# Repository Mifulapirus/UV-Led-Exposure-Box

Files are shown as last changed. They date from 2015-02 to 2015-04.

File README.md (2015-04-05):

# README #

UV LED exposure box

### What is this repository for? ###

* This project contains all the required information, hardware and software to make your own UV LED exposure machine so you can create your own PCBs at home.

### Materials ###
* Here is the list of all the different parts you need to build your own UV-LED Exposure Box
* https://docs.google.com/spreadsheets/d/1VbFTGXd1PagAe3uoOmZKsPFVGucdBjDqCyi8I9-2VKY/edit?usp=sharing

### Contact ###
* @mifulapirus

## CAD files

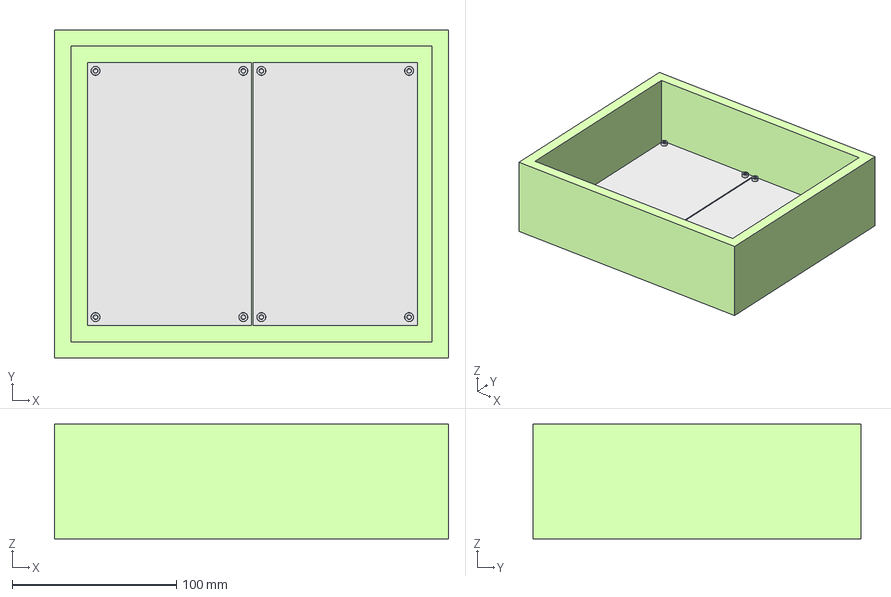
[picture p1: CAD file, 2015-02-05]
Hardware/Box/Bottom.FCStd
240.0 x 200.0 x 70.0 mm
PCB1_Completa
PCB2_Completa

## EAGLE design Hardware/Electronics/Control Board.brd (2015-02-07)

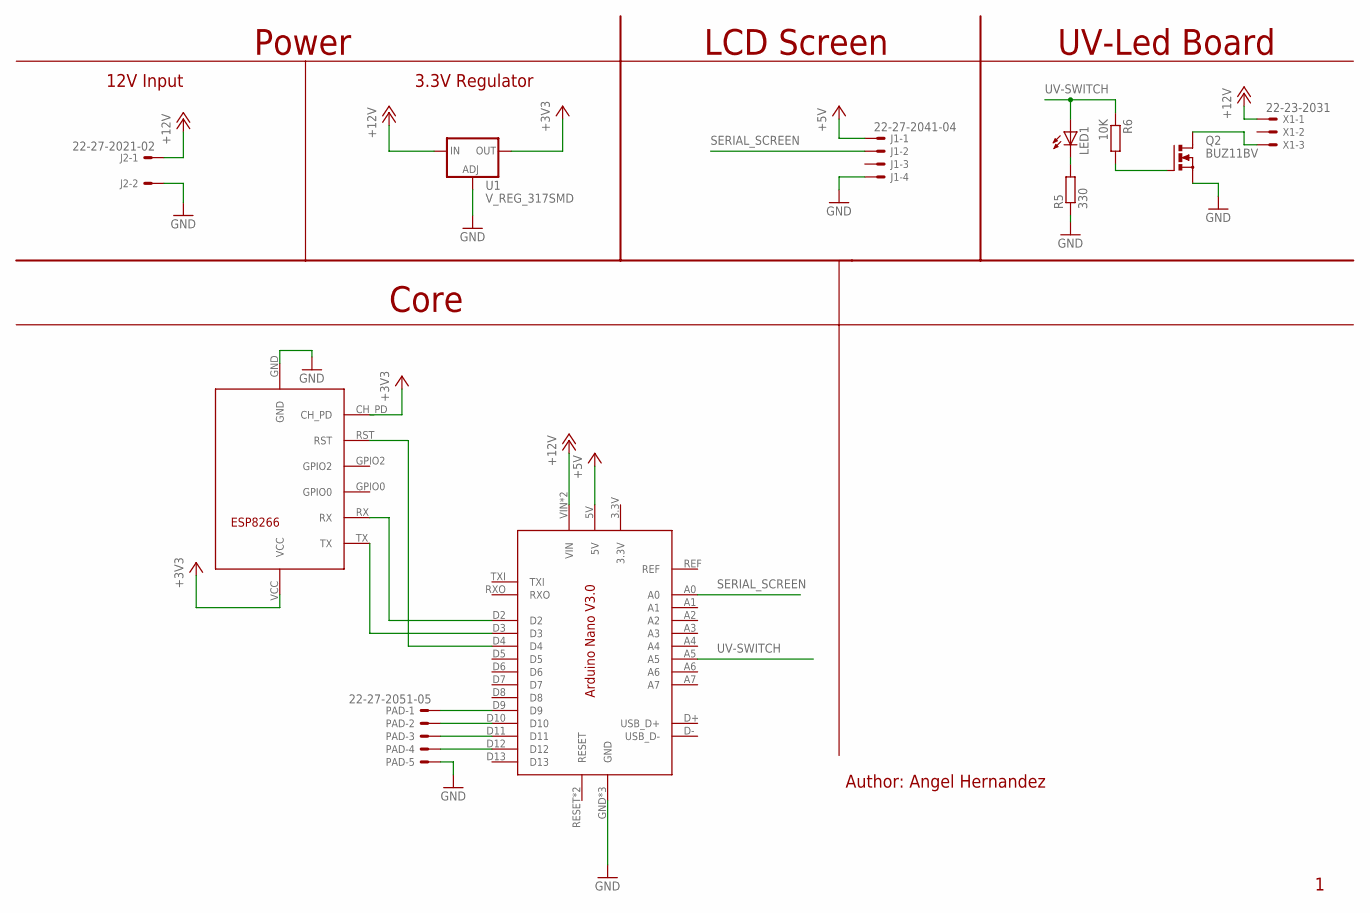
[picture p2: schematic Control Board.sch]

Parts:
J1: 22-27-2041-04; 6410-04
J2: 22-27-2021-02; 6410-02
LED1: LED3MM
PAD: 22-27-2051-05; 6410-05
Q2: BUZ11BV; TO220BV
R5: 330; 0204/7
R6: 10K; 0204/7
U1: V_REG_317SMD; SOT223
U$1: ARDUINO_NANO_V3
U$2: ESP8266
X1: 22-23-2031

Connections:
+3V3: U1.2 (OUT), U$2.CH_PD, U$2.VCC
+5V: J1.1, U$1.5V
+12V: J2.1, U1.3 (IN), U$1.VIN, U$1.VUSB (VIN), X1.1
GND: J1.4, J2.2, PAD.5, Q2.S, R5.1, U1.1 (ADJ), U$1.GND, U$1.GND1 (GND), U$1.GND_USB (GND), U$2.GND
unnamed: Q2.D, X1.3
unnamed: U$1.D3, U$2.TX
unnamed: U$1.D2, U$2.RX
unnamed: PAD.1, U$1.D9
unnamed: PAD.2, U$1.D10
unnamed: PAD.3, U$1.D11
unnamed: PAD.4, U$1.D12
unnamed: LED1.K (C), R5.2
unnamed: Q2.G, R6.2
unnamed: U$1.D4, U$2.RST
SERIAL_SCREEN: J1.2, U$1.A0
UV-SWITCH: LED1.A, R6.1, U$1.A5

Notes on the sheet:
UV-Led Board
Power
LCD Screen
Author: Angel Hernandez
12V Input
3.3V Regulator
Core

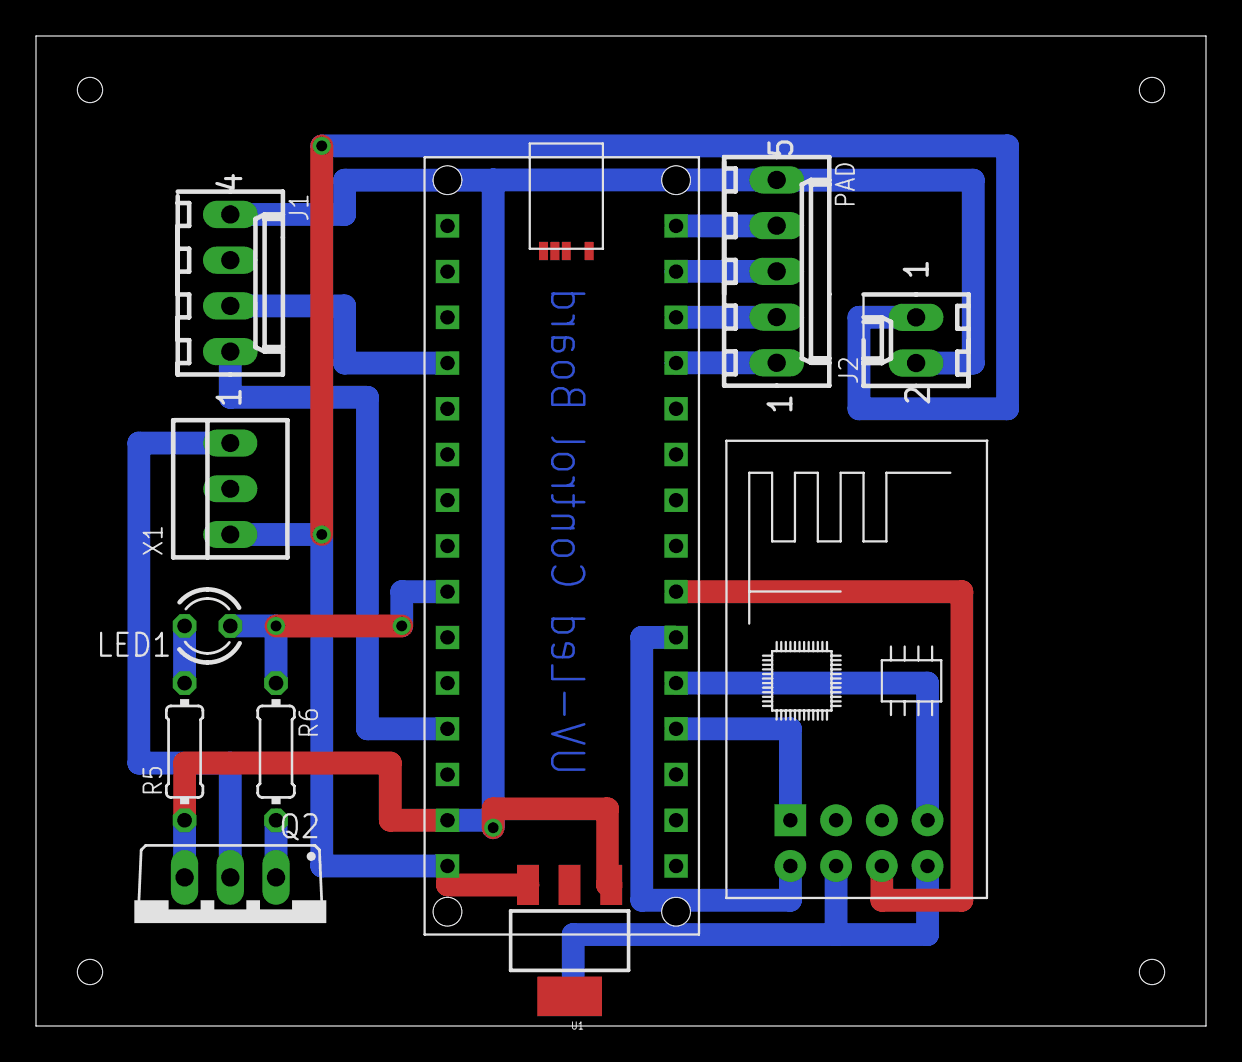
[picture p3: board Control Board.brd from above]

Board: 2 copper layers, 65.0 x 55.0 mm, 11 parts (0 on the bottom side), 16 nets.

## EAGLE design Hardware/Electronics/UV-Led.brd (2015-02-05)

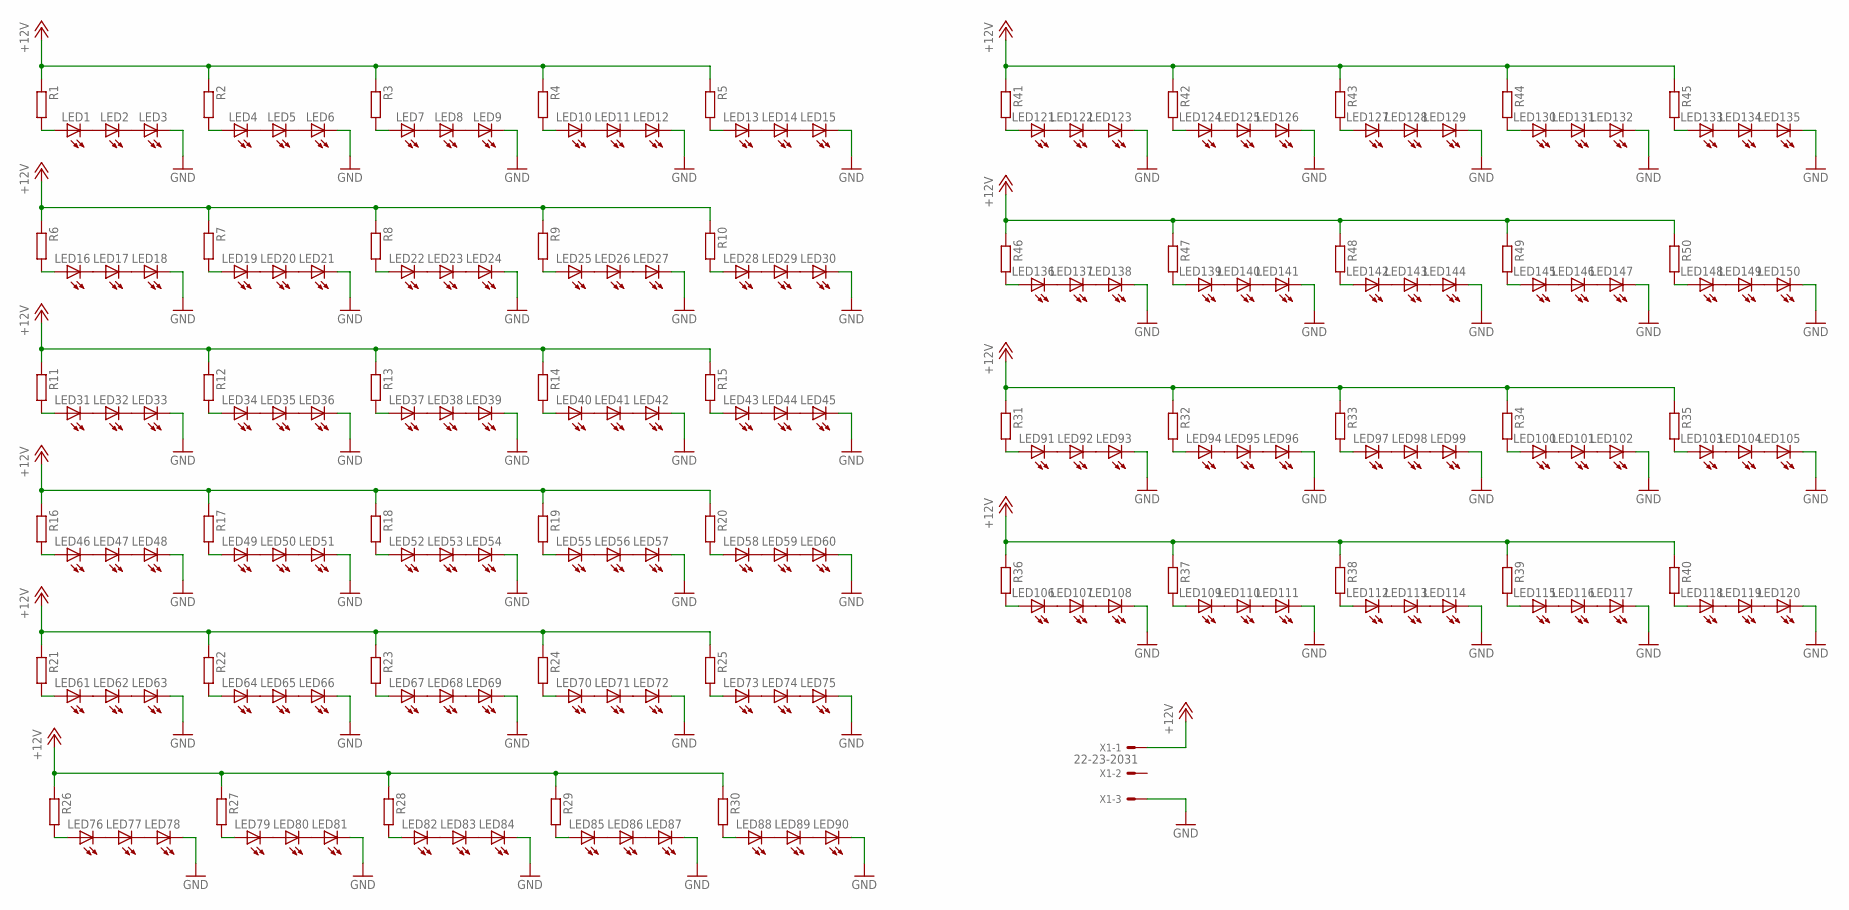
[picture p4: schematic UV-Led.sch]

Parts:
LED1, LED2, LED3, LED4, LED5, LED6, LED7, LED8, LED9, LED10, LED11, LED12, LED13, LED14, LED15, LED16, LED17, LED18, LED19, LED20, LED21, LED22, LED23, LED24, LED25, LED26, LED27, LED28, LED29, LED30, LED31, LED32, LED33, LED34, LED35, LED36, LED37, LED38, LED39, LED40, LED41, LED42, LED43, LED44, LED45, LED46, LED47, LED48, LED49, LED50, LED51, LED52, LED53, LED54, LED55, LED56, LED57, LED58, LED59, LED60, LED61, LED62, LED63, LED64, LED65, LED66, LED67, LED68, LED69, LED70, LED71, LED72, LED73, LED74, LED75, LED76, LED77, LED78, LED79, LED80, LED81, LED82, LED83, LED84, LED85, LED86, LED87, LED88, LED89, LED90, LED91, LED92, LED93, LED94, LED95, LED96, LED97, LED98, LED99, LED100, LED101, LED102, LED103, LED104, LED105, LED106, LED107, LED108, LED109, LED110, LED111, LED112, LED113, LED114, LED115, LED116, LED117, LED118, LED119, LED120, LED121, LED122, LED123, LED124, LED125, LED126, LED127, LED128, LED129, LED130, LED131, LED132, LED133, LED134, LED135, LED136, LED137, LED138, LED139, LED140, LED141, LED142, LED143, LED144, LED145, LED146, LED147, LED148, LED149, LED150: LED5MM
R1, R2, R3, R4, R5, R6, R7, R8, R9, R10, R11, R12, R13, R14, R15, R16, R17, R18, R19, R20, R21, R22, R23, R24, R25, R26, R27, R28, R29, R30, R31, R32, R33, R34, R35, R36, R37, R38, R39, R40, R41, R42, R43, R44, R45, R46, R47, R48, R49, R50: R-EU_0207/10; 0207/10
X1: 22-23-2031

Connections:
+12V: R1.1, R2.1, R3.1, R4.1, R5.1, R6.1, R7.1, R8.1, R9.1, R10.1, R11.1, R12.1, R13.1, R14.1, R15.1, R16.1, R17.1, R18.1, R19.1, R20.1, R21.1, R22.1, R23.1, R24.1, R25.1, R26.1, R27.1, R28.1, R29.1, R30.1, R31.1, R32.1, R33.1, R34.1, R35.1, R36.1, R37.1, R38.1, R39.1, R40.1, R41.1, R42.1, R43.1, R44.1, R45.1, R46.1, R47.1, R48.1, R49.1, R50.1, X1.1
GND: LED3.K (C), LED6.K (C), LED9.K (C), LED12.K (C), LED15.K (C), LED18.K (C), LED21.K (C), LED24.K (C), LED27.K (C), LED30.K (C), LED33.K (C), LED36.K (C), LED39.K (C), LED42.K (C), LED45.K (C), LED48.K (C), LED51.K (C), LED54.K (C), LED57.K (C), LED60.K (C), LED63.K (C), LED66.K (C), LED69.K (C), LED72.K (C), LED75.K (C), LED78.K (C), LED81.K (C), LED84.K (C), LED87.K (C), LED90.K (C), LED93.K (C), LED96.K (C), LED99.K (C), LED102.K (C), LED105.K (C), LED108.K (C), LED111.K (C), LED114.K (C), LED117.K (C), LED120.K (C), LED123.K (C), LED126.K (C), LED129.K (C), LED132.K (C), LED135.K (C), LED138.K (C), LED141.K (C), LED144.K (C), LED147.K (C), LED150.K (C), X1.3
unnamed: LED1.K (C), LED2.A
unnamed: LED2.K (C), LED3.A
unnamed: LED4.K (C), LED5.A
unnamed: LED5.K (C), LED6.A
unnamed: LED7.K (C), LED8.A
unnamed: LED8.K (C), LED9.A
unnamed: LED1.A, R1.2
unnamed: LED4.A, R2.2
unnamed: LED7.A, R3.2
unnamed: LED13.K (C), LED14.A
unnamed: LED10.K (C), LED11.A
unnamed: LED11.K (C), LED12.A
unnamed: LED10.A, R4.2
unnamed: LED14.K (C), LED15.A
unnamed: LED13.A, R5.2
unnamed: LED16.K (C), LED17.A
unnamed: LED17.K (C), LED18.A
unnamed: LED19.K (C), LED20.A
unnamed: LED20.K (C), LED21.A
unnamed: LED22.K (C), LED23.A
unnamed: LED23.K (C), LED24.A
unnamed: LED16.A, R6.2
unnamed: LED19.A, R7.2
unnamed: LED22.A, R8.2
unnamed: LED25.K (C), LED26.A
unnamed: LED26.K (C), LED27.A
unnamed: LED28.K (C), LED29.A
unnamed: LED29.K (C), LED30.A
unnamed: LED25.A, R9.2
unnamed: LED28.A, R10.2
unnamed: LED31.K (C), LED32.A
unnamed: LED32.K (C), LED33.A
unnamed: LED34.K (C), LED35.A
unnamed: LED35.K (C), LED36.A
unnamed: LED37.K (C), LED38.A
unnamed: LED38.K (C), LED39.A
unnamed: LED31.A, R11.2
unnamed: LED34.A, R12.2
unnamed: LED37.A, R13.2
unnamed: LED40.K (C), LED41.A
unnamed: LED41.K (C), LED42.A
unnamed: LED43.K (C), LED44.A
unnamed: LED44.K (C), LED45.A
unnamed: LED40.A, R14.2
unnamed: LED43.A, R15.2
unnamed: LED46.K (C), LED47.A
unnamed: LED47.K (C), LED48.A
unnamed: LED49.K (C), LED50.A
unnamed: LED50.K (C), LED51.A
unnamed: LED52.K (C), LED53.A
unnamed: LED53.K (C), LED54.A
unnamed: LED46.A, R16.2
unnamed: LED49.A, R17.2
unnamed: LED52.A, R18.2
unnamed: LED55.K (C), LED56.A
unnamed: LED56.K (C), LED57.A
unnamed: LED58.K (C), LED59.A
unnamed: LED59.K (C), LED60.A
unnamed: LED55.A, R19.2
unnamed: LED58.A, R20.2
unnamed: LED61.K (C), LED62.A
unnamed: LED62.K (C), LED63.A
unnamed: LED64.K (C), LED65.A
unnamed: LED65.K (C), LED66.A
unnamed: LED67.K (C), LED68.A
unnamed: LED68.K (C), LED69.A
unnamed: LED61.A, R21.2
unnamed: LED64.A, R22.2
unnamed: LED67.A, R23.2
unnamed: LED70.K (C), LED71.A
unnamed: LED71.K (C), LED72.A
unnamed: LED73.K (C), LED74.A
unnamed: LED74.K (C), LED75.A
unnamed: LED70.A, R24.2
unnamed: LED73.A, R25.2
unnamed: LED76.K (C), LED77.A
unnamed: LED77.K (C), LED78.A
unnamed: LED79.K (C), LED80.A
unnamed: LED80.K (C), LED81.A
unnamed: LED82.K (C), LED83.A
unnamed: LED83.K (C), LED84.A
unnamed: LED76.A, R26.2
unnamed: LED79.A, R27.2
unnamed: LED82.A, R28.2
unnamed: LED85.K (C), LED86.A
unnamed: LED86.K (C), LED87.A
unnamed: LED88.K (C), LED89.A
unnamed: LED89.K (C), LED90.A
unnamed: LED85.A, R29.2
unnamed: LED88.A, R30.2
unnamed: LED91.K (C), LED92.A
unnamed: LED92.K (C), LED93.A
unnamed: LED94.K (C), LED95.A
unnamed: LED95.K (C), LED96.A
unnamed: LED97.K (C), LED98.A
unnamed: LED98.K (C), LED99.A
unnamed: LED91.A, R31.2
unnamed: LED94.A, R32.2
unnamed: LED97.A, R33.2
unnamed: LED100.K (C), LED101.A
unnamed: LED101.K (C), LED102.A
unnamed: LED103.K (C), LED104.A
unnamed: LED104.K (C), LED105.A
unnamed: LED100.A, R34.2
unnamed: LED103.A, R35.2
unnamed: LED106.K (C), LED107.A
unnamed: LED107.K (C), LED108.A
unnamed: LED109.K (C), LED110.A
unnamed: LED110.K (C), LED111.A
unnamed: LED112.K (C), LED113.A
unnamed: LED113.K (C), LED114.A
unnamed: LED106.A, R36.2
unnamed: LED109.A, R37.2
unnamed: LED112.A, R38.2
unnamed: LED115.K (C), LED116.A
unnamed: LED116.K (C), LED117.A
unnamed: LED118.K (C), LED119.A
unnamed: LED119.K (C), LED120.A
unnamed: LED115.A, R39.2
unnamed: LED118.A, R40.2
unnamed: LED121.K (C), LED122.A
unnamed: LED122.K (C), LED123.A
unnamed: LED124.K (C), LED125.A
unnamed: LED125.K (C), LED126.A
unnamed: LED127.K (C), LED128.A
unnamed: LED128.K (C), LED129.A
unnamed: LED121.A, R41.2
unnamed: LED124.A, R42.2
unnamed: LED127.A, R43.2
unnamed: LED130.K (C), LED131.A
unnamed: LED131.K (C), LED132.A
unnamed: LED133.K (C), LED134.A
unnamed: LED134.K (C), LED135.A
unnamed: LED130.A, R44.2
unnamed: LED133.A, R45.2
unnamed: LED136.K (C), LED137.A
unnamed: LED137.K (C), LED138.A
unnamed: LED139.K (C), LED140.A
unnamed: LED140.K (C), LED141.A
unnamed: LED142.K (C), LED143.A
unnamed: LED143.K (C), LED144.A
unnamed: LED136.A, R46.2
unnamed: LED139.A, R47.2
unnamed: LED142.A, R48.2
unnamed: LED145.K (C), LED146.A
unnamed: LED146.K (C), LED147.A
unnamed: LED148.K (C), LED149.A
unnamed: LED149.K (C), LED150.A
unnamed: LED145.A, R49.2
unnamed: LED148.A, R50.2

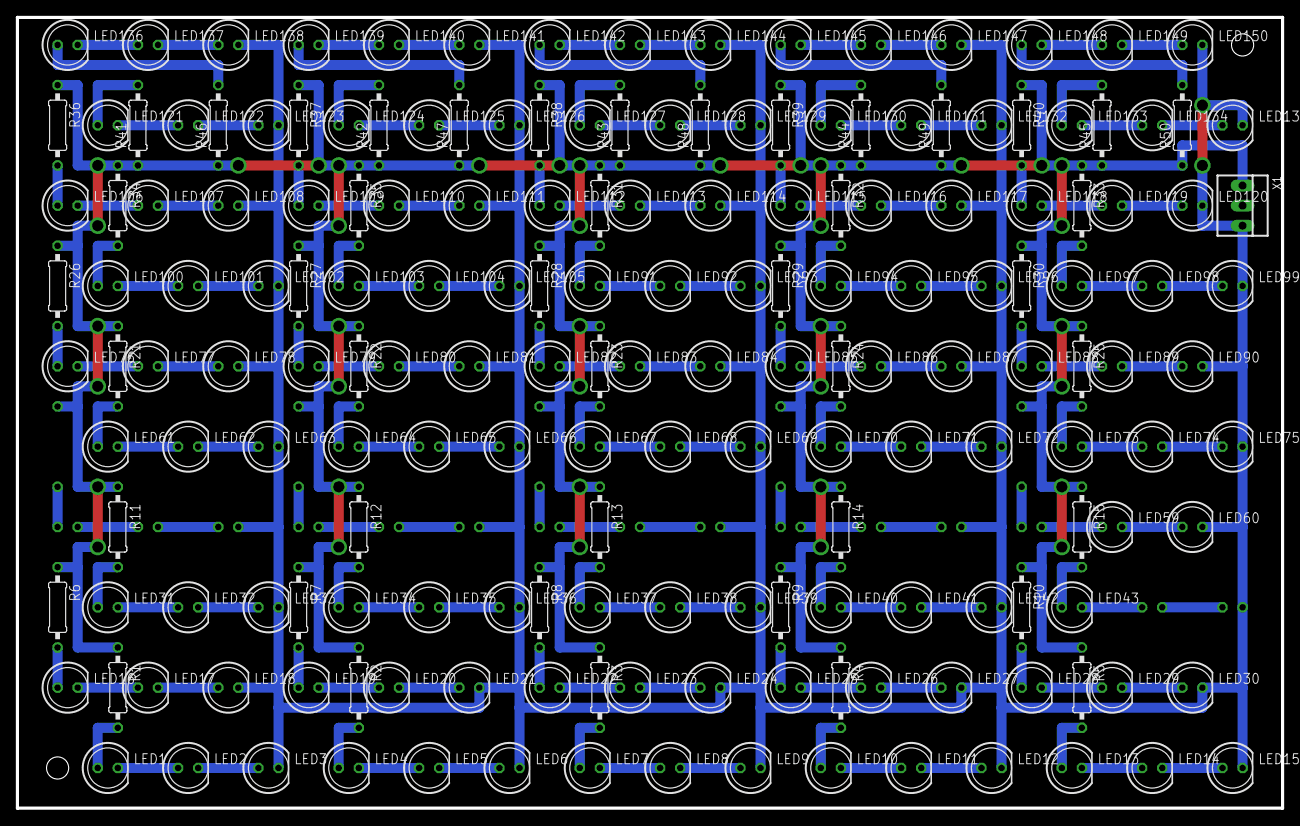
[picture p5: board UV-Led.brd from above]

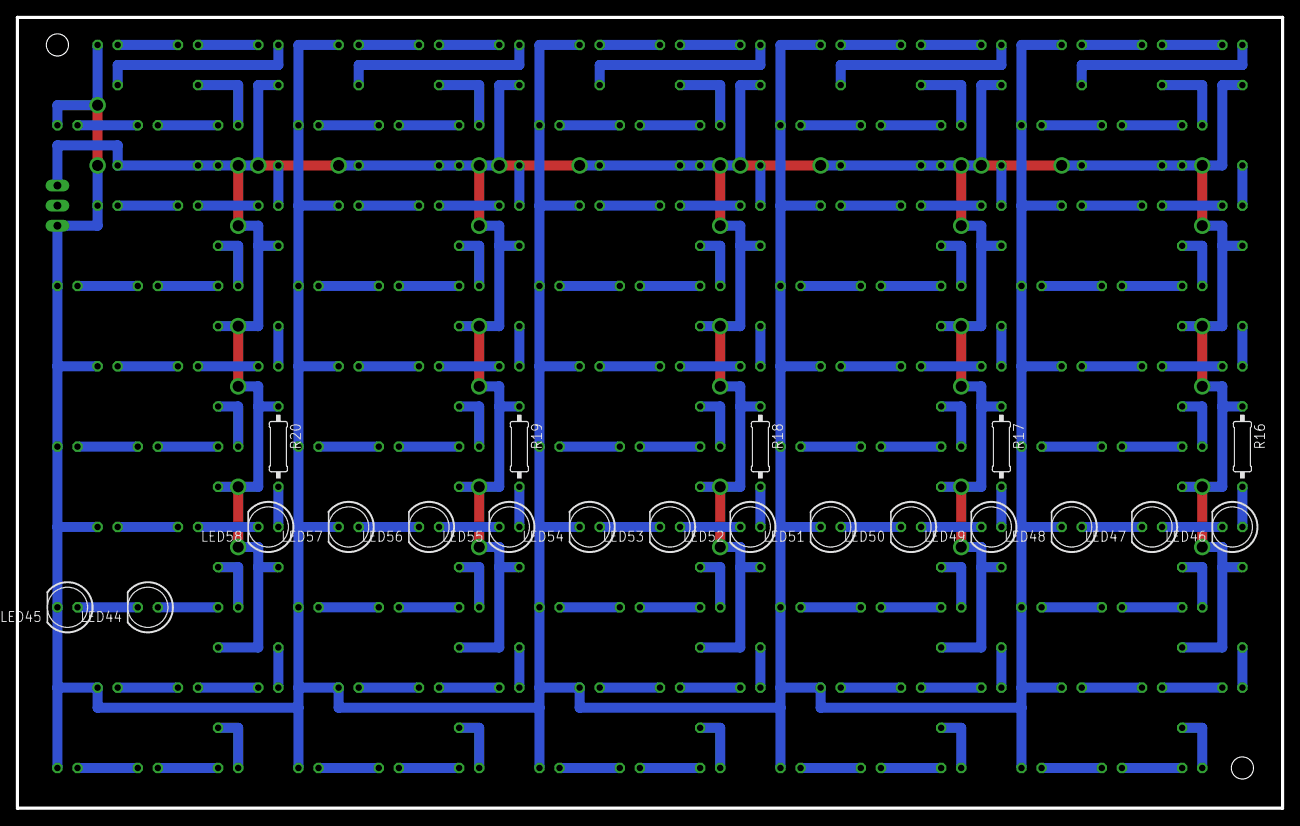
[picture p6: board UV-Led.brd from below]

Board: 2 copper layers, 160.0 x 100.0 mm, 201 parts (20 on the bottom side), 152 nets.

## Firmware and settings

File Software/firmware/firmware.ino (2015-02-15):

#include <SoftwareSerial.h>
#include <ESP8266.h>
#include <serLCD.h>

/*******************************
* Pin definitions
*******************************/
#define DISPLAY_PIN   A1

#define PAD_UP_PIN    9
#define PAD_DOWN_PIN  10
#define PAD_LEFT_PIN  11
#define PAD_RIGHT_PIN 12

#define UV_SWITCH_PIN A5

#define WIFI_RX_PIN 2
#define WIFI_TX_PIN 3
#define WIFI_RST_PIN 4

/*******************************
* General variables
*******************************/
#define FIRMWARE_VERSION   "0.2"
#define DEVICE_CATEGORY    "UV Exposure Box" 
#define DEVICE_NAME        "UV Exposure Box"
long timerStartedTime = 0;
long timerLastUpdate   = 0;
long timerValue       = 10000;         //10 seconds
boolean timerStarted = false;

/*****************************
* Other devices
*****************************/
serLCD lcd(DISPLAY_PIN);

/*******************************
* WiFi Stuff
*******************************/
#define BAUD 9600
#define SSID "Interne"
#define PASS "Mec0mebien"
#define SERVER_PORT  "5555"
ESP8266 wifi(WIFI_RX_PIN, WIFI_TX_PIN, WIFI_RST_PIN, BAUD);

/****************************
* Control Commands
****************************/
#define CMD_UV_ON    "UV:On"
#define CMD_UV_OFF   "UV:Off"
#define CMD_UV_TEST  "UV:Test"
#define CMD_TIMER_ON  "Timer:On"
#define CMD_TIMER_ON  "Timer:Off"
#define CMD_SET_TIMER  "SetTimer"
#define CMD_START_TIMER  "StartTimer"
#define CMD_STOP_TIMER  "StopTimer"

/****************************
* Configuration Commands
****************************/
#define CMD_WIFI_SSID  "SetSSID"
#define CMD_WIFI_PASS  "SetPass"



/************************************
* Setup and initializations
************************************/  
void setup() {
  //Set input pins
  pinMode(PAD_UP_PIN, INPUT);
  pinMode(PAD_DOWN_PIN, INPUT);
  pinMode(PAD_LEFT_PIN, INPUT);
  pinMode(PAD_RIGHT_PIN, INPUT);
  //Set output pins
  pinMode(WIFI_RST_PIN, OUTPUT);
  pinMode(UV_SWITCH_PIN, OUTPUT);
  
  //Initialize navite serial port
  Serial.begin(9600);
  lcd.clear();
  delay(1000);
  bootUp(); 
}


/************************************
* printing and reporting
************************************/
void lcdAndSerialPrint(String _text) {
  lcd.print(_text);
  Serial.println(_text);
}


/************************************
* General Functions
************************************/
void loop() {
  receiveCommand();
  checkUVTimer();
}

//Bootup sequence
void bootUp() {
  int _err = -1;
  int Err = -1;
  lcd.clear();
  lcdAndSerialPrint(DEVICE_NAME);
  lcd.selectLine(2);
  lcdAndSerialPrint("Version: ");
  lcdAndSerialPrint(FIRMWARE_VERSION);
  
  delay(1000);
  lcd.clear();
  lcdAndSerialPrint("UV Test -> ");
  UVSwithTest();
  lcdAndSerialPrint("Done");
  delay(1000);
  
  lcd.clear();
  lcdAndSerialPrint("Initializing");
  lcd.selectLine(2);
  lcdAndSerialPrint("WiFi ESP8266");
  _err = wifi.init(SSID, PASS);
  if(_err != NO_ERROR) {
    lcdAndSerialPrint("Error: ");
    lcdAndSerialPrint(String(_err));
    delay(3000);
  }
  
  else{
    lcd.clear();
    lcdAndSerialPrint("Connected: ");
    lcd.selectLine(2);
    lcdAndSerialPrint(wifi.IP);
    delay(2000);  
  }
     
  _err = wifi.setServer(SERVER_PORT);
  if(_err != NO_ERROR) {
    lcd.clear();
    lcdAndSerialPrint("Error: ");
    lcdAndSerialPrint(String(_err));
  }
  
  else{
    lcd.clear();
    lcdAndSerialPrint("Server OK: ");
    lcdAndSerialPrint(wifi.serverPort);
    
    delay(1000);
    lcd.clear();
    lcdAndSerialPrint(DEVICE_NAME);
    lcd.selectLine(2);
    lcdAndSerialPrint("     ONLINE");  
  }    
}


/**************************************************************************************
* Command functions
***************************************************************************************/
int receiveCommand() {
  String _cmd = wifi.readCmd();
  if (_cmd == "") return false;
  if (_cmd == CMD_UV_ON)                  return setUV(true);
  else if (_cmd == CMD_UV_OFF)            return setUV(false);
  else if (_cmd == CMD_UV_TEST)           return UVSwithTest();
  else if (contains(_cmd, CMD_SET_TIMER)) return setTimer(extractParam(_cmd).toInt());
  else if (_cmd == CMD_START_TIMER)       return startTimer();
  else if (_cmd == CMD_STOP_TIMER)        return stopTimer();
  else return false;
}

boolean contains(String _original, String _search) {
    int _searchLength = _search.length();
	int _max = _original.length() - _searchLength;
    for (int i = 0; i <= _max; i++) {
        if (_original.substring(i, i+_searchLength) == _search) {return true;}
    }
    return false;
} 

//Extracts the value of a parameter from the '=' separator till the end
String extractParam(String _cmd) {
  int _separatorIndex = _cmd.indexOf('=') + 1;
  return _cmd.substring(_separatorIndex);
}

  
/**************************************************************************************
* UV-LED Functions
***************************************************************************************/
boolean UVSwithTest() {
  for (int i=0; i<4; i++) {
   digitalWrite(UV_SWITCH_PIN, !digitalRead(UV_SWITCH_PIN));
   delay(200);
  }
  return true;
}

boolean setUV(boolean _state) {
   digitalWrite(UV_SWITCH_PIN, _state);
   getUV();
   if (digitalRead(UV_SWITCH_PIN)== _state) return true;
   else return false;
}

boolean getUV() {
  boolean _state = digitalRead(UV_SWITCH_PIN);
  lcd.setCursor(2,16);
  lcd.print(_state);
  return _state;
}

void toggleUV() {
  digitalWrite(UV_SWITCH_PIN, !digitalRead(UV_SWITCH_PIN));
}

void checkUVTimer() {
  if (timerStarted == true) {
    long _now = millis();
        
    if (_now > (timerStartedTime + timerValue - 1000)) {
      setUV(false);
      timerStarted = false;
      lcd.clear();
      lcdAndSerialPrint("Exposure DONE");
    }
    
    else if (_now >= timerLastUpdate + 1000) {  //Every second print remaining time
      timerLastUpdate = _now;
      lcd.setCursor(2,1);
      lcd.print("               ");
      lcd.setCursor(2,1);
      lcdAndSerialPrint(String((timerStartedTime + timerValue - _now)/1000));
    }  
  }
}

boolean setTimer(int _time) {
  timerValue = _time;
  timerValue = timerValue * 1000;  //time converted to ms
  lcd.setCursor(2,1);
  lcd.print("               ");
  lcd.setCursor(2,1);
  lcdAndSerialPrint(String(timerValue/1000));
  return true;
}
  
boolean startTimer() {
    timerStarted = true;
    timerStartedTime=millis();
    setUV(true);
    return true;
}

boolean stopTimer() {
    timerStarted = false;
    setUV(false);
    return true;
}

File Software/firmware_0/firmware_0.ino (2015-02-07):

#include <SoftwareSerial.h>
#include <serLCD.h>

#define display_pin A0

#define padUp_pin 9
#define padDown_pin 10
#define padLeft_pin 11
#define padRight_pin 12

#define UVSwitch_pin A5


/*******************************
* General variables
*******************************/
#define FirmwareVersion "0.1"
#define DeviceCategory "UV Exposure Box" 
int DeviceID = 1; 
#define DeviceName "UV"

/*******************************
* WiFi Stuff
*******************************/
#define wifiRx_pin 2
#define wifiTx_pin 3
#define wifiRST_pin 4

#define SSID "Interne"
#define PASS "Mec0mebien"
SoftwareSerial WiFiSerial(wifiRx_pin, wifiTx_pin); // RX, TX
String OwnIP = "000.000.000.000";
String WiFiLongMessage;

//----------------------
//Messages sent
#define ResponseOK     "OK"
#define Error          "ERROR "
  #define ErrorUnableToLink             "1"
  #define SendLongMessageError          "2"  
  #define ErrorModuleDoesntRespond      "3"
  #define ErrorModuleDoesntRespondToAT  "4"
  #define ErrorResponseNotFound         "5"
  #define ErrorUnableToConnect          "6"
  
#define CIPSTART       "AT+CIPSTART=\"TCP\",\""


serLCD lcd(display_pin);


void setup() {
  pinMode(padUp_pin, OUTPUT);
  pinMode(padDown_pin, OUTPUT);
  pinMode(padLeft_pin, OUTPUT);
  pinMode(padRight_pin, OUTPUT);
  pinMode(wifiRST_pin, OUTPUT);
  pinMode(UVSwitch_pin, OUTPUT);
  
  Serial.begin(9600);
  WiFiSerial.begin(9600);
  
  Serial.println(DeviceName);
  Serial.println(DeviceCategory);
  Serial.print("V. ");
  Serial.println(FirmwareVersion);
  Serial.print("ID: ");
  Serial.println(DeviceID);
  //Attach the interruption
//  attachInterrupt(0, FireDetected, RISING);
  WiFiLongMessage.reserve(400);
  lcd.clear();
  lcd.print(DeviceCategory);
  lcd.print(" ");
  lcd.print(FirmwareVersion);
  UVSwithTest();
  
  InitWiFi();
  lcd.print(" WiFi: Online");
}

/************************************
* General Functions
************************************/
void loop() {

}

void PrintError(char* ErrorMessage) {
  Serial.print(Error);
  Serial.println(ErrorMessage);
  }


/**************************************************************************************
* UV-LED Functions
***************************************************************************************/
void UVSwithTest() {
  for (int i=0; i<6; i++) {
   digitalWrite(UVSwitch_pin, !digitalRead(UVSwitch_pin));
   delay(500);
   }
}

/**************************************************************************************
* WiFi Functions
***************************************************************************************/
boolean OpenTCP(String IP, String Port) {
  String cmd = CIPSTART; 
  cmd += IP;
  cmd += "\",";
  cmd += Port;
  SendDebug(cmd);
  if (!ExpectResponse("Linked")) {
    PrintError(ErrorUnableToLink);
    return false;
  }
  return true;
}

boolean SendLongMessage(char* ExpectedReply) {
  Serial.println("Sending: ");
  Serial.println(WiFiLongMessage);
  WiFiSerial.print("AT+CIPSEND=");
  WiFiSerial.println(WiFiLongMessage.length());
  delay(200); 
  WiFiSerial.print(WiFiLongMessage);
  if (ExpectResponse(ExpectedReply)) {
    Serial.println(ResponseOK);
    return true;
    }
  else {
    PrintError(SendLongMessageError);
    return false;
    }
}

void WiFiRead() {
    while (WiFiSerial.available()) {
      Serial.write(WiFiSerial.read());
      delay(1);
    }
}  

void WiFiEcho() {
  while(1) {
    if (WiFiSerial.available())
      Serial.write(WiFiSerial.read());
    if (Serial.available())
      WiFiSerial.write(Serial.read());
  }
}

void SendDebug(String cmd) {
  WiFiSerial.flush();
  Serial.print("Sent: ");
  Serial.println(cmd);
  WiFiSerial.println(cmd);
}

boolean CloseTCP() {
  SendDebug("AT+CIPCLOSE");
  if (!ExpectResponse("Unlink")) {CheckWiFi();}
}


boolean InitWiFi() {
  while (!WiFiReboot())  {}
  //while (!CheckWiFi())   {}
  while (!ConnectWiFi()) {}
  SetCIPMODE(false);
  return true;
}

boolean WiFiReboot() {
  digitalWrite(wifiRST_pin, LOW);
  delay(500);
  digitalWrite(wifiRST_pin, HIGH);
  if (ExpectResponse("Ready")) {
    return true;  
  }
  else {
    PrintError(ErrorModuleDoesntRespond);
    return false;
  }
}

boolean WiFiReset() {
  WiFiSerial.flush();
  Serial.println("Reboot");
  WiFiSerial.println("AT+RST"); // restet and test if module is redy
  if (ExpectResponse("Ready")) {
    return true;  
  }
  else {
    PrintError(ErrorModuleDoesntRespond);
    return false;
  }
}

boolean CheckWiFi() {
  SendDebug("AT");
  if (ExpectResponse(ResponseOK)) {
    Serial.println(ResponseOK);
    return true;
  }
  else {
    PrintError(ErrorModuleDoesntRespondToAT);
    InitWiFi();
    return false;
  }
}

boolean ExpectResponse(char* _Expected) {
  Serial.print("Waiting for ");
  Serial.print(_Expected);
  Serial.print(": ");

  for (int i = 0; i < 10; i++) {
    if (WiFiSerial.find(_Expected)) {
      Serial.println(_Expected);
      return true;
    }

    else {
      //TODO: Do something if not found yet?
      Serial.print(".");
    }
    delay(1);
  }
  PrintError(ErrorResponseNotFound);
  return false;
}

String GetIP() {
  WiFiSerial.flush();
  WiFiSerial.println("AT+CIFSR"); // Get IP
  OwnIP = "";
  char incomingByte = ' ';
  delay(100);
  while (WiFiSerial.available() > 0) {
    // read the incoming byte:
    incomingByte = WiFiSerial.read();
    // say what you got:
    OwnIP += incomingByte;
    delay(1);
  }
  return OwnIP;
}

boolean ConnectWiFi() {
  WiFiSerial.flush();
  Serial.println("Connecting");
  WiFiSerial.println("AT+CWMODE=1");
  delay(2000);
  String cmd = "AT+CWJAP=\"";
  cmd += SSID;
  cmd += "\",\"";
  cmd += PASS;
  cmd += "\"";
  SendDebug(cmd);
  if (ExpectResponse(ResponseOK)) {
    Serial.print("IP: ");
    Serial.println(GetIP());
  }
  else {
    PrintError(ErrorUnableToConnect);
  }
}

boolean SetCIPMODE(boolean Value) {
  if (Value) {WiFiSerial.println("AT+CIPMODE=1");}
  else {WiFiSerial.println("AT+CIPMODE=0");}
}

int CheckBaudrate() {
  //300, 600, 1200, 2400, 4800, 9600, 14400, 19200, 28800, 31250, 38400, 57600, and 115200. 
  int Pause=500;
  long Baudrate[13] = {300, 600, 1200, 2400, 4800, 9600, 14400, 19200, 28800, 31250, 38400, 57600, 115200};
  
  for (int i=0; i<13; i++) {
    WiFiSerial.begin(Baudrate[i]);
    Serial.print("\n\r ");
    Serial.print(Baudrate[i]);
    Serial.print(": ");
    WiFiReboot();
    WiFiRead();
  }
}

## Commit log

2015-02-05 Initial commit - Bottom side of the box
    [Bottom.FCStd]
2015-02-05 Electronics - Initial version of the UV-Led board
    [UV-Led.brd, UV-Led.sch]
2015-02-06 Electronics - Control board Rev.0
    [Control Board.brd, Control Board.sch]
2015-02-07 Intermediate commit - needs improvement
    [Control Board.brd, Control Board.sch]
2015-02-07 Electronics - Working version
    [Control Board.brd, Control Board.sch]
2015-02-09 Regular Commit - Added Support for ESP8266 - Added Commands - Bug fixes
    [firmware.ino]

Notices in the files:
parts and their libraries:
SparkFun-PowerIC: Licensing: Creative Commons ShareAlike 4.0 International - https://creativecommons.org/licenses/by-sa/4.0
